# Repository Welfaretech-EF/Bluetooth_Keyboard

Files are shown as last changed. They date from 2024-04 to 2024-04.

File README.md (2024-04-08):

# Bluetooth Keyboard
This project presents a simple 8 port programmable bluetooth keyboard. Each port can be controlled using a 3.5mm minijack switch and is able to send standard HID-signals through Bluetooth, making it possible to connect to a vast amount of devices, such as smartphones and laptops.

# Requirements
* ESP32 Development Board
* 8x Female 3.5mm socket

# Assembly
In order to assemble the circuit, the following fritzing sketch has been designed. The pin headers used are instead of the 3.5mm mono sockets, for using a standard 0/1-switch.
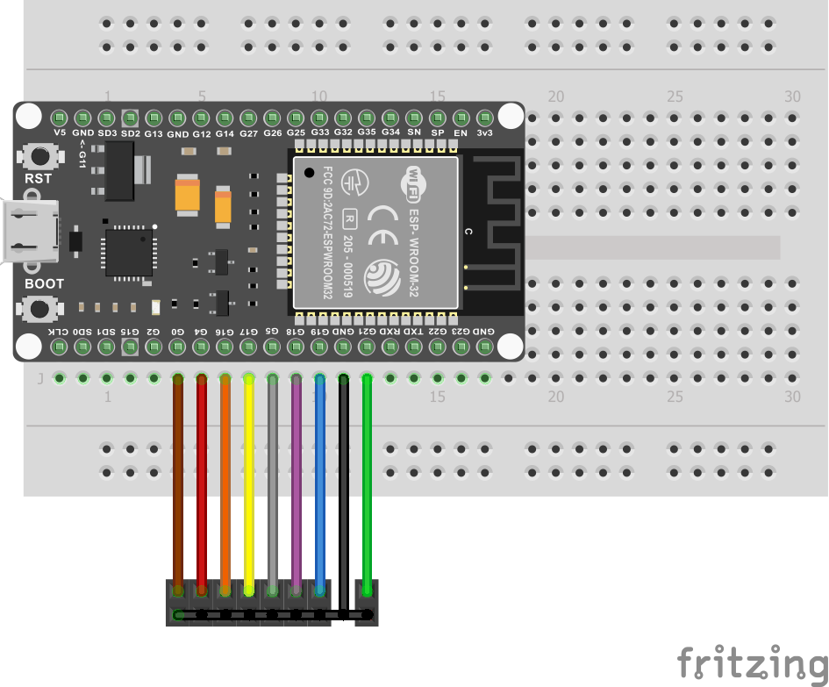
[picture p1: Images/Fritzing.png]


# Customization
Once the Bluetooth keyboard is powered on and connected to the receiving device, the 8 ports can control the 8 inputs. In order to customize the inputs, it is possible to connect to the local wifi-hotspot and accessing a local website on: http://192.168.1.1
# 3D Printed case
A 3d printable custom case has been designed, enclosing all the electronics. All the stl files can be found in the "3D Models" folder.

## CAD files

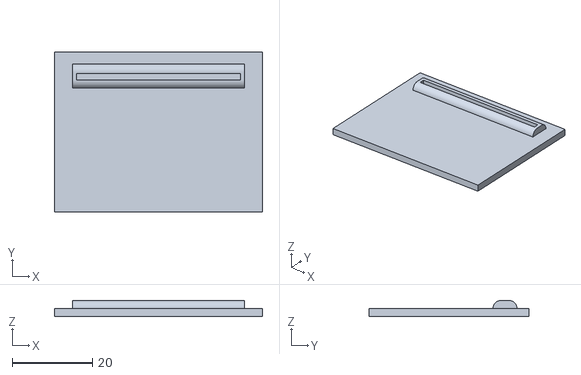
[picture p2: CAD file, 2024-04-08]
3D Models/Bluetooth Keyboard - No button.stl
52.0 x 40.0 x 4.00

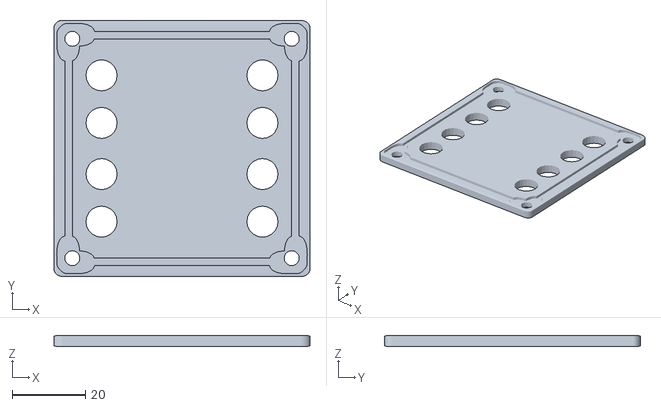
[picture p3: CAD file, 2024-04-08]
3D Models/Bluetooth Keyboard - TopMinijack.stl
70.0 x 70.0 x 3.00

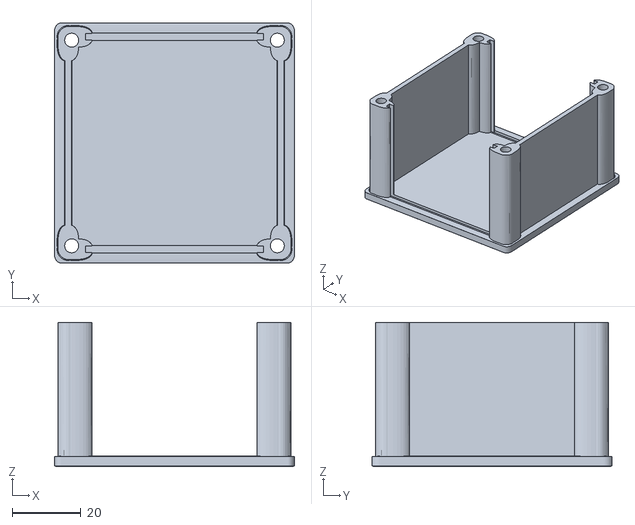
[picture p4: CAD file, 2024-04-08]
3D Models/Bluetooth Keyboard - Box.stl
70.0 x 70.0 x 42.0

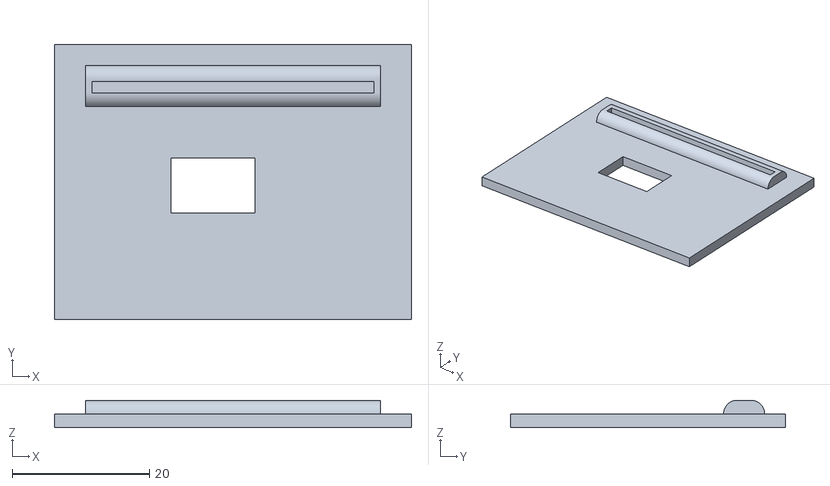
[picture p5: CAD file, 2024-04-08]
3D Models/Bluetooth Keyboard - Arduino.stl
52.0 x 40.0 x 4.00

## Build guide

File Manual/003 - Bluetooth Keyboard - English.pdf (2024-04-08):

# Guide to 003_Bluetooth Keyboard

(Turn on by connecting the device to power via the USB connector on the side)

## Connect device (laptop, smartphone, ...) as a normal keyboard

1. Under bluetooth settings, search for new devices and connect to "Elsass Keyboard" (Elsass Bluetooth" for old version).
2. By pressing 0/1 switches connected to the 8 channels, the unit will send the preset keys to the receiver.

## Change the keyboard setup

The reprogramming of the individual switches is done via Wifi and can be changed from another device than the one connected via Bluetooth.
1. On a device (laptop, smartphone, ...) search for wireless networks. Connect to "Elsass Keyboard" or whatever the device has been renamed to, as this can also be changed.
a. For some devices, it may be necessary to accept the connection to the network.
2. Open any browser (Chrome, Edge, Firefox, ...) and type 192.168.1.1 in the address field.
3. By changing the list for the 8 channels and then pressing "Submit" you can specify what the 8 channels activate.
a. If you are sitting on a PC with English language, you can select "En" at the top.
4. (Requires update to the latest version!): If you want to change the name for Wifi and/or Bluetooth, this is also done via the corresponding boxes - however, this requires the device to be restarted, by briefly disconnecting the USB plug and then reconnecting the USB.

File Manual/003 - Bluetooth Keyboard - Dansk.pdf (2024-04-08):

# Guide til 003_Bluetooth Keyboard

(Tænd ved at tilslutte enheden til strøm via USB-stikket på siden)

## Forbind enhed (laptop, smarthone, …) som almindeligt keyboard

1. Under bluetooth-indstillingerne søges efter nye enheder og der oprettes forbindelse til ”Elsass Keyboard”(Elsass Bluetooth” for gammel version).
2. Ved tryk på 0/1-kontakter der er forbundet til de 8 kanaler, vil enheden sende de forudindstillede taster til modtageren.

## Ændre opsætningen for keyboardet

For at ændre på de taster der sendes ved aktivering af de 8 kanaler, er det muligt at omprogrammere disse. Da dette foregår via Wifi, kan en anden enhed bruges, end den der er koblet op via Bluetooth.

1. På en enhed (laptop, smartphone, …) søges efter trådløse netværk. Forbind til ”Elsass Keyboard” eller det som netværket er angivet til, da dette også kan ændres.
a. For nogle enheder kan det være nødvendigt at acceptere at der oprettes forbindelse til netværket.
2. Åben en vilkårlig browser (Chrome, Edge, Firefox, …) og skriv 192.168.1.1 i adressefeltet.
3. Ved at ændre i listen for de 8 kanaler og derefter trykke på ”Submit” kan man angive hvad de 8 kanaler aktiverer.
a. Hvis man sidder på en pc med engelsk sprog, kan man vælge ”En” i toppen.
4. (Kræver opdatering til nyeste version!): Hvis man ønsker at ændre navnet for Wifi og/eller Bluetooth, gøres dette ligeledes via de tilhørende felter – det kræver dog at enheden genstartes, ved at frakoble usb-stikket kortvarigt og derefter tilkoble usb-stikket igen.

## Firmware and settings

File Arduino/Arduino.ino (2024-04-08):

/*

Created by: Simon Kjems Jørgensen (2020-08-08)
Modified by: Mikkel Damgaard Justiniano (2023-07-19)
Organsation: The Elsass Foundation

This is a Bluetooth keyboard that is configurable
to send most normal and frequently used keys.

It uses a webserver to be configured with
a simple webinterface. 

The esp32 must be configured to use huge 
partition (3mb no OTA / 1mb SPIFFS)
*/

//Includes 
//Wifi used to configurer the BleKeyboard
#include <WiFi.h>

//Handle the bluetooth low energy keyboard
#include "BleKeyboard.h"
#include "BleMouse.h"

#include <Preferences.h>

struct Button {
    const uint8_t PIN;
    uint32_t iKey;
    uint32_t lastChange;
    bool isPressed;
};

Button buttons[] = {
  {5,104,0,false},
  {18,106,0,false},
  {19,105,0,false},
  {21,107,0,false},
  {0,0,0,false},
  {4,96,0,false},
  {16,97,0,false},
  {17,98,0,false}
};

uint8_t nButtons;

int nAsciis;
int nKeys;
int nMediaKeys;

//Set the name of the bluetooth keyboard
BleKeyboard bleKeyboard("Elsass Keyboard");
//BleMouse bleMouse("Elsass Mouse");

//Webserver config
IPAddress local_ip(192, 168, 1, 1);
IPAddress gateway(192, 168, 1, 1);
IPAddress subnet(255, 255, 255, 0);

//Create webserver on port 80
WiFiServer server(80);

//Setup preferences
Preferences preferences;

bool isDK = true;
String wifiName;
String blName;
void loadPreferences(){
  Serial.println("Loading previous settings");
  preferences.begin("Elsass", false);
  isDK = preferences.getBool("isDK", true);
  wifiName = preferences.getString("wifiName", "Elsass Keyboard");
  blName = preferences.getString("blName", "Elsass Keyboard");
  bleKeyboard.setName(blName.c_str());
  if(isDK){
    Serial.println("Language: DK");
  }else{
    Serial.println("Language: EN");
  }
  
  Serial.println("Wifi Name: " + wifiName);
  Serial.println("Bluetooth Name: " + blName);
  
  for(int i = 0; i < nButtons; i++){
    String iStr = String(i);
    int key = preferences.getUInt(iStr.c_str(), -1);
    if(key != -1){
      buttons[i].iKey = key;
    }
    Serial.println("Button" + String(i) + " = " + String(buttons[i].iKey));
  }
  preferences.end();
}

String sendHTML(){
  String html = R"HTML(<!DOCTYPE html><html><head><meta charset="utf-8" name="viewport" http-equiv="Content-Type" content="width=device-width, initial-scale=1.0"> 
<title>Elsass</title><link rel="icon" href="data:,">
<style>
select{
  margin-top: 4px;
  width: 50%;
  margin-left:25%;
}
.select-selected {
  background-color: DodgerBlue;
}
div {
  width: 50%;
  margin: 0 auto;
  position: relative;
} 
.hover:hover {
    cursor: pointer;
}
form {  
  border-radius:5px
  border-color: gray;  
  border-width: 5px;  
  border-style: double;  
}
</style></head>
<body>
<form action="Change">Keyboard layout<br/>)HTML";
if(isDK){
  html+= R"HTML(<input style="background:green;color:white;" type="submit" name="language" value="DK" disabled><input class="hover" style="background:white;color:black" type="submit" name="language" value="EN">)HTML";
}else{
  html+= R"HTML(<input class="hover" style="background:white;color:black" type="submit" name="language" value="DK"><input style="background:green;color:white" type="submit" name="language" value="EN" disabled>)HTML";
}
html+="</form>";
html+= R"HTML(
  <br/>)HTML";
html+= "<form action=\"Reset\" onsubmit=\"alert('The device will now restart and you might need to reconnect')\">";
html+="<input class=\"hover\" style=\"width: 100%;background-color:#4CAF50;color:white;padding:14px 20px;margin: 8px 0;border: none;border-radius: 4px\" type=\"submit\" value=\"Reset (Will restart the device)\"></form><br/>";
html+= "<form action=\"Rename\" onsubmit=\"alert('The device will now restart and you might need to reconnect')\"><label for=\"wifi\">Wifi Name:</label><br/><input type=\"text\" id=\"wifi\" name=\"wifi\" value=\"" + wifiName + "\"><br/>";
html+= "<label for=\"bluetooth\">Bluetooth Name:</label><br/><input type=\"text\" id=\"bluetooth\" name=\"bluetooth\" value=\"" + blName + "\"><br/>";
html+= "<input class=\"hover\" style=\"width: 100%;background-color:#4CAF50;color:white;padding:14px 20px;margin: 8px 0;border: none;border-radius: 4px\" type=\"submit\" value=\"Save Names (Will restart the device)\"></form>";
html+= R"HTML(
    <br/><form action="Change"><div id = "content"></div>
    <input class="hover" style="width: 100%;background-color:#4CAF50;color:white;padding:14px 20px;margin: 8px 0;border: none;border-radius: 4px" type="submit" value="Save Buttons"></form>
  </form>
</body>
)HTML";

html += "<script>var def = ";
html += "[";
for(int i = 0; i < nButtons; i++){
  if(i != 0){
    html += ",";
  }
  html += buttons[i].iKey;
}
html += "];";
html += "\r\nvar str = [";
for(int i = 0; i < nAsciis;i++){
  if(i != 0){
    html += ",";
  }
  if(isDK){
    html += "\"" + asciis[i].str + "\"";
  }
  else{
    html += "\"" + asciisEN[i].str + "\"";
  }
}
for(int i = 0; i < nKeys;i++){
  html += ",\"" + keys[i].str + "\"";
}
for(int i = 0; i < nMediaKeys;i++){
  html += ",\"" + MediaKeyReports[i].str + "\"";
}

html += "];";
// Create HTML code to swithc keyboard layout (DK or EN)
html += R"HTML(
var text = "";
for (var i = 0; i < def.length; i++){
  text += "#" + (i+1) + "<select name=\"button";
  text += i;
  text += "\">";
  for (var j = 0; j < str.length; j++) {
    text += "<option value=\"";
    text += j;
    if(def[i] == j){
      text += "\" selected=>";
    }else{
      text += "\">";
    }
    text += str[j];
    text += "</option>";
  }
  text += "</select><br/>";
}
document.getElementById("content").innerHTML = text;
</script>
</html>)HTML";
  return html;
}
void press(uint32_t iKey){
  if (iKey < nAsciis){
    if(isDK){
      bleKeyboard.press(asciis[iKey].code);
    }else{
      bleKeyboard.press(asciisEN[iKey].code);
    }
  }
  else if(iKey < nAsciis+nKeys){
    bleKeyboard.press(keys[iKey-nAsciis].code);
  }
  else{
    bleKeyboard.press(MediaKeyReports[iKey-nAsciis-nKeys].code);
  }
}
void release(uint32_t iKey){
  if (iKey < nAsciis){
    if(isDK){
      bleKeyboard.release(asciis[iKey].code);
    }else{
      bleKeyboard.release(asciisEN[iKey].code);
    }
  }
  else if(iKey < nAsciis+nKeys){
    bleKeyboard.release(keys[iKey-nAsciis].code);
  }
  else{
    bleKeyboard.release(MediaKeyReports[iKey-nAsciis-nKeys].code);
  }
}

void isr(void* arg) {
  Button* s = static_cast<Button*>(arg);
  if(millis()-s->lastChange>10){
    if(digitalRead(s->PIN) == s->isPressed){
      s->lastChange = millis();
      s->isPressed = !s->isPressed;
      if(s->isPressed){
        press(s->iKey);
      }else{
        release(s->iKey);
      }
    }
  }
}

void setup(){
  nButtons = sizeof(buttons)/sizeof(buttons[0]);
  nAsciis = sizeof(asciis)/sizeof(asciis[0]);
  nKeys = sizeof(keys)/sizeof(keys[0]);
  nMediaKeys = sizeof(MediaKeyReports)/sizeof(MediaKeyReports[0]);

  //Begin serial communication on speed 115200
  Serial.begin(115200);

  //Get the lastest data from the preferences
  loadPreferences();

  //Begin the BLE keyboard/start advertising the keyboard
  Serial.print("Setting up BLE");
  bleKeyboard.begin();
  Serial.println(" - Done");

  //To limit errors
  delay(2000);

  //Button pins
  Serial.print("Setting up PINS");
  for(int i = 0; i < nButtons;i++){
    pinMode(buttons[i].PIN, INPUT_PULLUP);
    attachInterruptArg(buttons[i].PIN, isr, &buttons[i], CHANGE);
  }
  Serial.println(" - Done");

  //To limit errors
  delay(100);
  
  Serial.print("Setting up WIFI");
  WiFi.softAP(wifiName.c_str());
  WiFi.softAPConfig(local_ip, gateway, subnet);
  Serial.println(" - Done");
  
  //To limit errors
  delay(100);

  //Start the server
  Serial.print("Starting server");
  server.begin();
  Serial.println(" - Done");

  Serial.println("Setup Finished");
}

String getHTML(String line,String id){
  String result = "";
  int i0 = line.indexOf(id);
  if(i0 != -1){
    int i1 = line.indexOf("=",i0);
    if(i1 != -1){
      int i2 = i1+1;
      int i3 = line.indexOf("&",i2);
      if(i3 == -1){
        i3 = line.indexOf(" ",i2);
        if(i3 != -1){
          result = line.substring(i2,i3);
        }
      }else{
        result = line.substring(i2,i3);
      }
    }
  }
  result.replace("+"," ");
  return result;
}

void handleServer(){
  WiFiClient client = server.available();
  if (client) {
    bool restart = false;
    String header = "";
    Serial.println("New Client.");
    String currentLine = "";
    bool get = false;
    
    while (client.connected()) {
      if (client.available()) {
        char c = client.read();
        header += c;
        if (c == '\n') {
          if (currentLine.length() != 0) {
            int iGet = currentLine.indexOf("GET");
            if(iGet != -1){
              if(currentLine.indexOf("Reset?")!=-1){
                Serial.println("Resetting and restarting");
                preferences.begin("Elsass", false);
                preferences.clear();
                preferences.end();
                restart = true;
              }
              else if(currentLine.indexOf("Rename?")!=-1){
                Serial.println("Changing names and restarting");
                String wifi = getHTML(currentLine,"wifi");
                if(wifi != ""){
                  get = true;
                  wifiName = wifi;
                  Serial.println("Wifi Name: " + wifiName);
                }
                String bluetooth = getHTML(currentLine,"bluetooth");
                if(bluetooth != ""){
                  get = true;
                  blName = bluetooth;
                  Serial.println("Bluetooth Name: " + blName);
                }
                preferences.begin("Elsass", false);
                preferences.putString("wifiName", wifiName);
                preferences.putString("blName", blName);
                preferences.end();
                restart = true;
              }else{
                String language = getHTML(currentLine,"language");
                if(language != ""){
                  get = true;
                  if(language.equals("DK")){
                    isDK = true;
                  }else if(language.equals("EN")){
                    isDK = false;
                  }
                  if(isDK){
                    Serial.println("Language: DK");
                  }else{
                    Serial.println("Language: EN");
                  }
                }
                for(int i = 0; i < nButtons;i++){
                  String button = getHTML(currentLine,"button"+String(i));
                  if(button != ""){
                    get = true;
                    buttons[i].iKey = button.toInt();
                    Serial.println("Button" + String(i) + " = " + button);
                  }
                }
                if(get){
                  preferences.begin("Elsass", false);
                  for (int i = 0; i < nButtons; i++){
                    String iStr = String(i);
                    preferences.putUInt(iStr.c_str(), buttons[i].iKey);
                  }
                  preferences.putBool("isDK", isDK);
                  preferences.putString("wifiName", wifiName);
                  preferences.putString("blName", blName);
                  preferences.end();
                }
      			  }
            }
            currentLine = "";
          }
          else{
            break;
          }
        } else if (c != '\r') {
          currentLine += c;
        }
      }
    }
    Serial.println(header);
    if(get){
        client.println("HTTP/1.1 200 OK");
        client.println("Content-type:text/html");
        client.println("Connection: close");
        client.println();
        client.println(R"HTML(<!DOCTYPE html><html><head><script>window.onload=function(){if ('referrer' in document) {window.location = document.referrer;} else {window.history.back();}};</script></head></html>)HTML");
    }
      else{
        client.println("HTTP/1.1 200 OK");
        client.println("Content-type:text/html");
        client.println("Connection: close");
        client.println();
        client.println(sendHTML());
    }
    
    header = "";
    // Close the connection
    client.stop();
    Serial.println("Client disconnected.");
    Serial.println("");
    if(restart){
      ESP.restart();
    }
  }
}
long lastServer = 0;
void loop(){
  if(abs(long(millis()-lastServer))>1000){
    handleServer();
    lastServer = millis();
  }
}
